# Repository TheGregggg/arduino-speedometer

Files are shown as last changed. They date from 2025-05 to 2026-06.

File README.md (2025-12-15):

# Arduino Speedometer
This is a speedometer for sim racing, built using an Arduino, a servo motor and a four-digit, eight-segment display.  

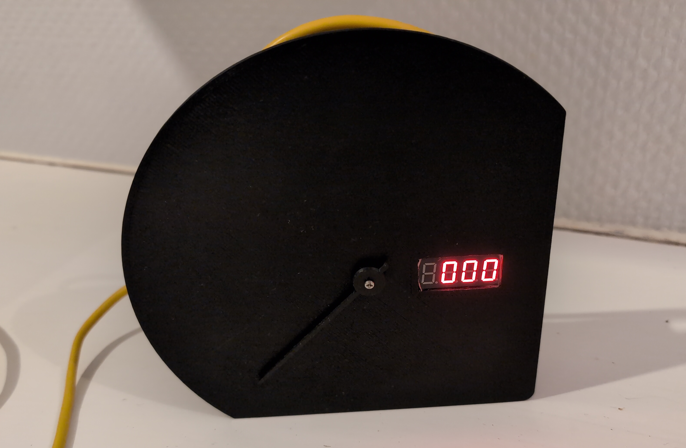
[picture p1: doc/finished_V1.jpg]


This speedometer displays analogue engine RPM via the servo motor and digital speed in km/h via the four-digit LED display.  

The server is programmed in C and currently support only Forza Horizon 4.
The game is configured to send data packets to the server. The server parses the packet and only uses the RPM and speed and send it to the Arduino via UART in a special byte format that compresses the RPM and the speed into 3 bytes.

## Planned improvements
- Update it to support other games, such as Forza Horizon 5 (not tested but should be straightforward) and Assetto Corsa (specific logic needs to be done for this game).  
- Improve visuals with a white dial across all the half circle.  
- Paint the needle red to make it more visible.  

# Build
I wanted to build something modular, reparable and with off the shelf components, specifically what I have lying around.

That's why I used an Arduino UNO as the microcontroller.
I also used a 3461BS as the 4 digits 8 segments display paired with a HC595 8 bit shift register.

The first prototype was realised with a breadboard and cardboard.
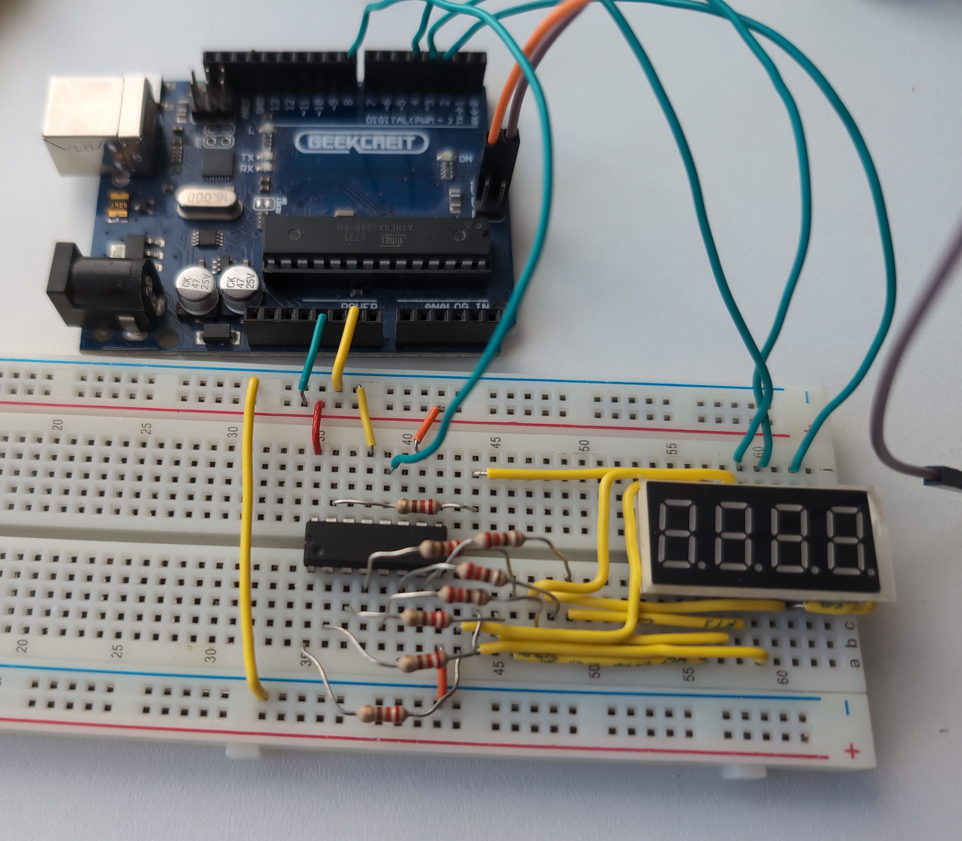
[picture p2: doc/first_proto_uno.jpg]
First protoype with the UNO and a breadboard

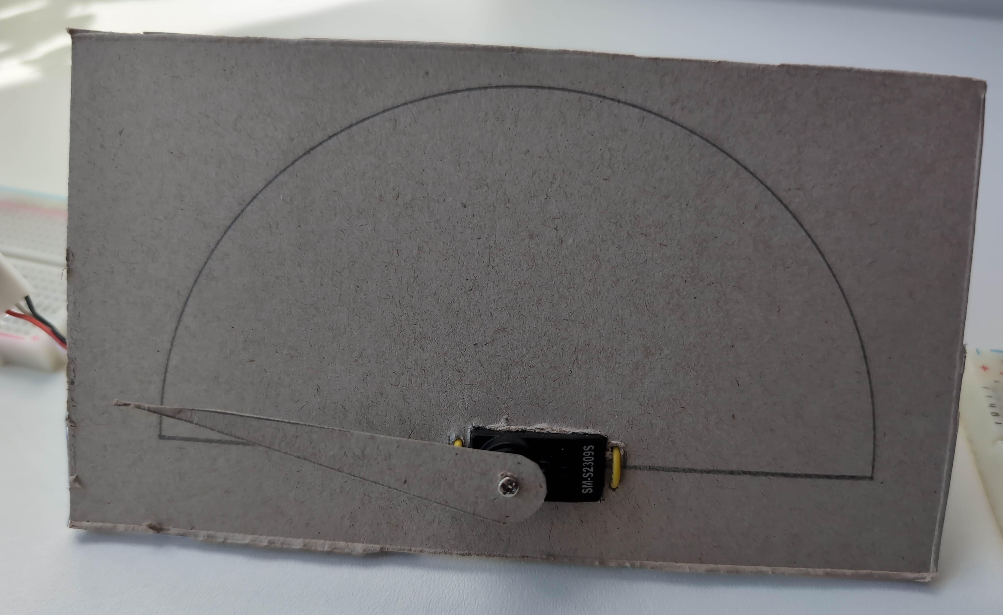
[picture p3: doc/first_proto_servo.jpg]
First protoype with the servo motor

*First prototype with all the components mounted on a breadboard and the servo attached to a cardboard dial*

I then created a custom board for all the components.
All the resistors, the DIP socket for the HC595 and a decoupling capacitor for the servo motor were mounted and soldered on a stripboard for a clean finished product.

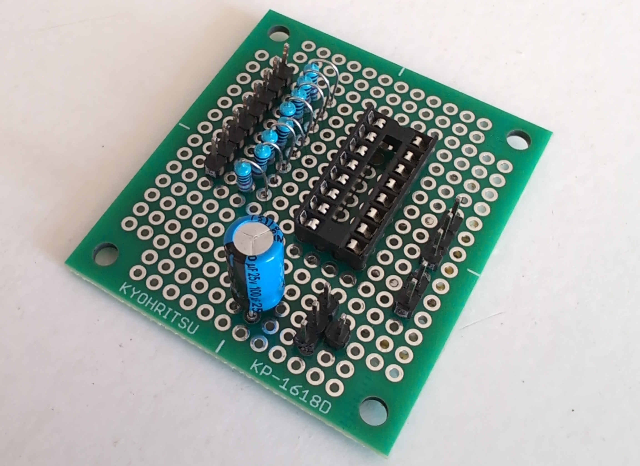
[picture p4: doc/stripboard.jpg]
Strip board with soldered components

*Hand soldered stripboard :) you don't want to look to the other way.*

Pins were also soldered to facilitate connections between this board and the Arduino and the 3461BS.

The custom board was tested with everything plugged in.
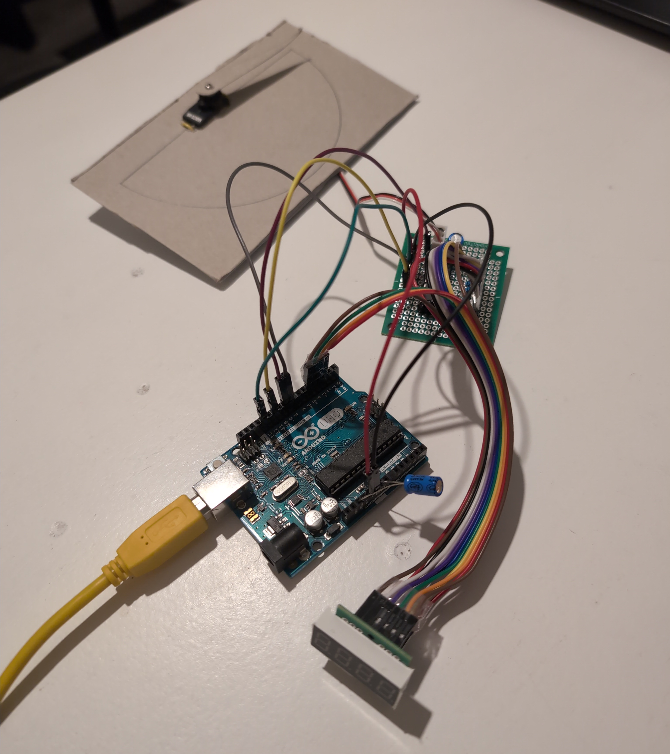
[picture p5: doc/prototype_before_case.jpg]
Prototype using the stripboard

*Prototype cardboard speedometer using the stripboard*

I designed the shell in FreeCAD to learn 3D modelling and then 3D printed it in PLA.
I then assembled everything into a tiny and neat product.

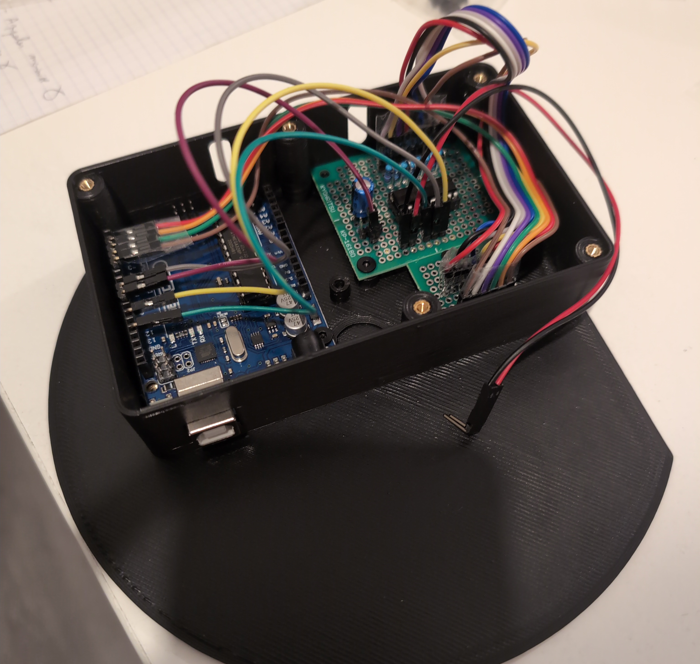
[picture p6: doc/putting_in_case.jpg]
Fitting all components inside the shell

*Fitting all components together in the tight shell. Threaded inserts were used to facilitate screw mounting of the components and to allow disassembly!*

# Work Reference
STEP files used as 3D reference for case design:  
- https://www.printables.com/model/360145-micro-servo-3d-model-stp/files
- https://www.printables.com/model/358867-arduino-uno-3d-model-stp/files

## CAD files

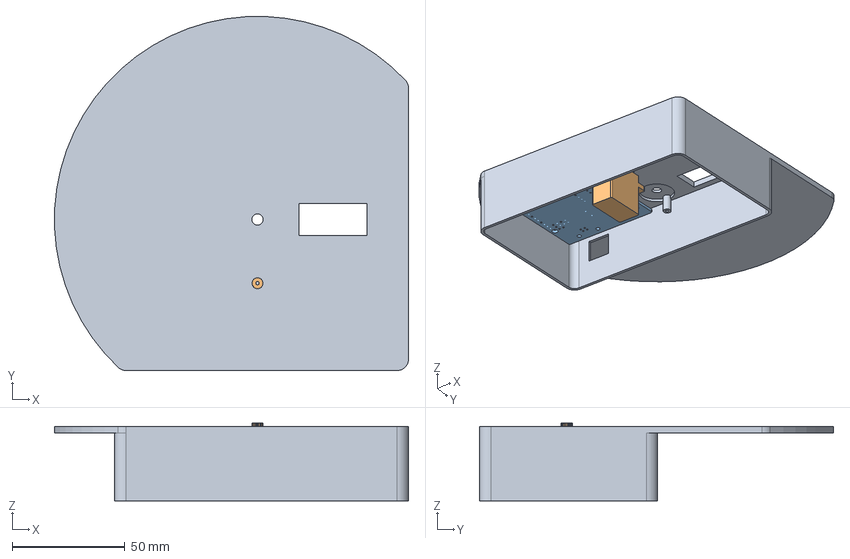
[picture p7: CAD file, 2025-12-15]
cad/shell_assembly.FCStd
156.8 x 156.8 x 34.5 mm
shell_Corps_001
SG90-Servo1_SG90-SERVO_001
UNO-TH_Rev3e1_001

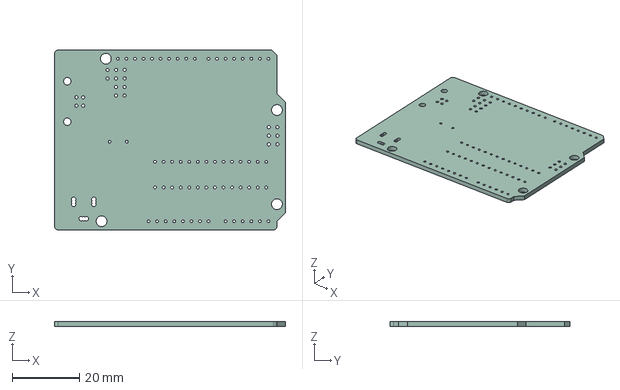
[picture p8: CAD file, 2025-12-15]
cad/A000066-cad-files/UNO-TH_Rev3e.step
68.6 x 53.3 x 1.51 mm

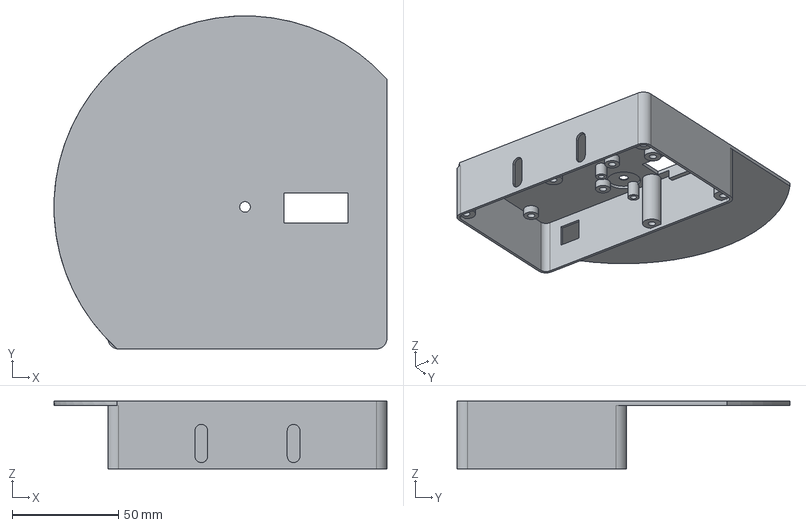
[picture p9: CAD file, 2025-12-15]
cad/shell-shell.step
156.9 x 156.8 x 32.0 mm

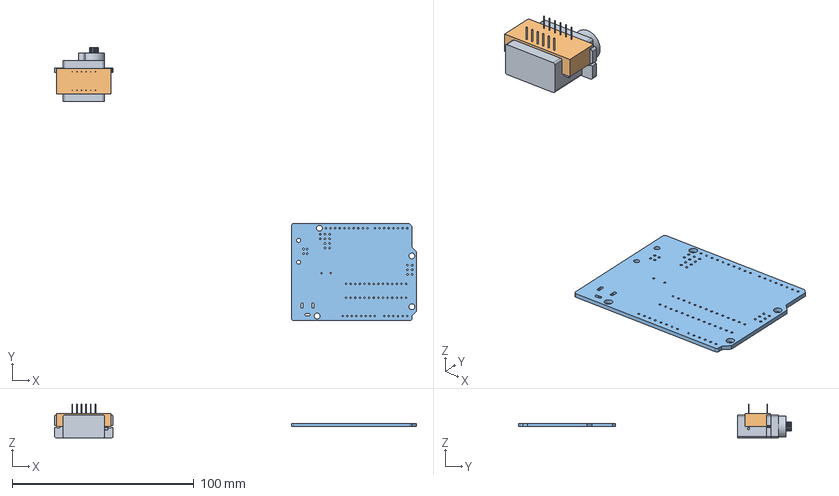
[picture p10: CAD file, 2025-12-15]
cad/shell.FCStd
198.9 x 150.2 x 18.4 mm
SG90-SERVO
Corps
UNO-TH_Rev3e_PCB

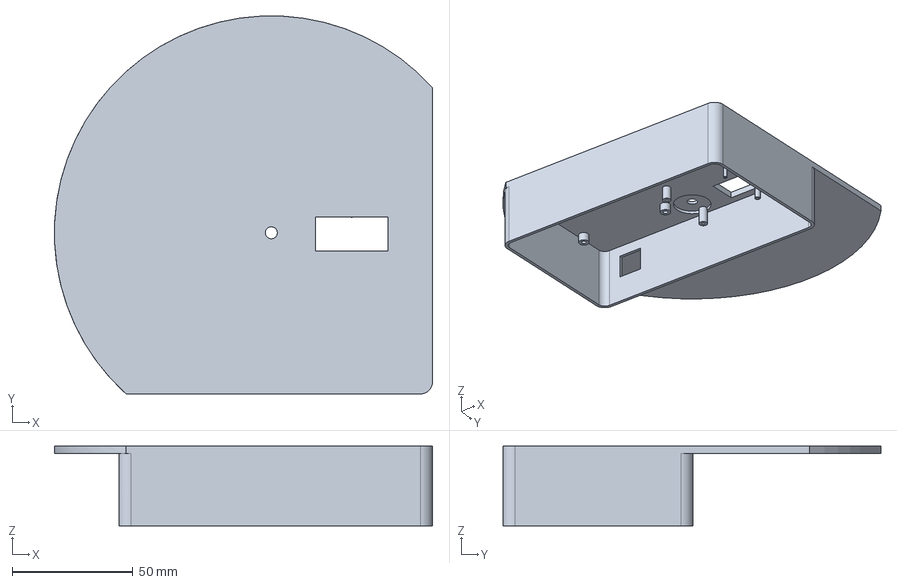
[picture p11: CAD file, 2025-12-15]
cad/shell.FCStd.bak.FCStd
156.8 x 156.8 x 33.0 mm

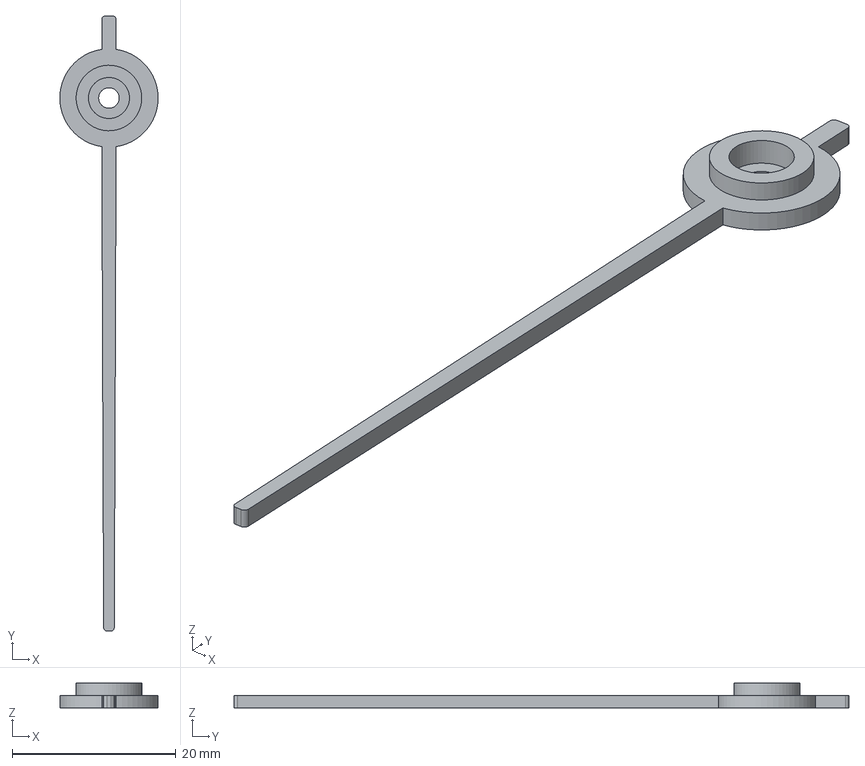
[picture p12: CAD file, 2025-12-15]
cad/aiguille.step
12.0 x 75.0 x 3.00 mm

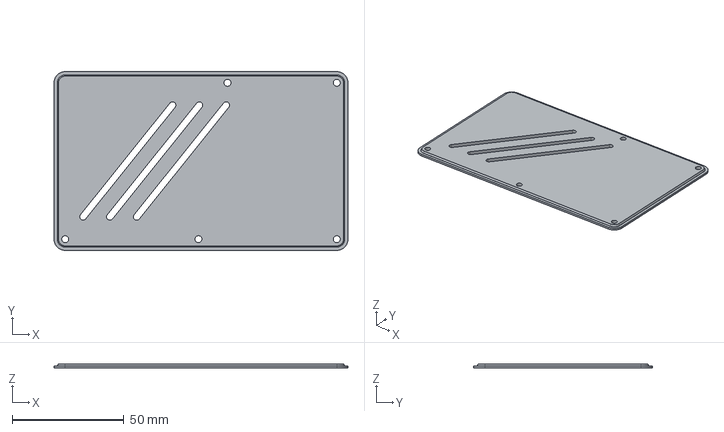
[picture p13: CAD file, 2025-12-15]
cad/shell-couvercle.step
131.5 x 79.9 x 2.00 mm

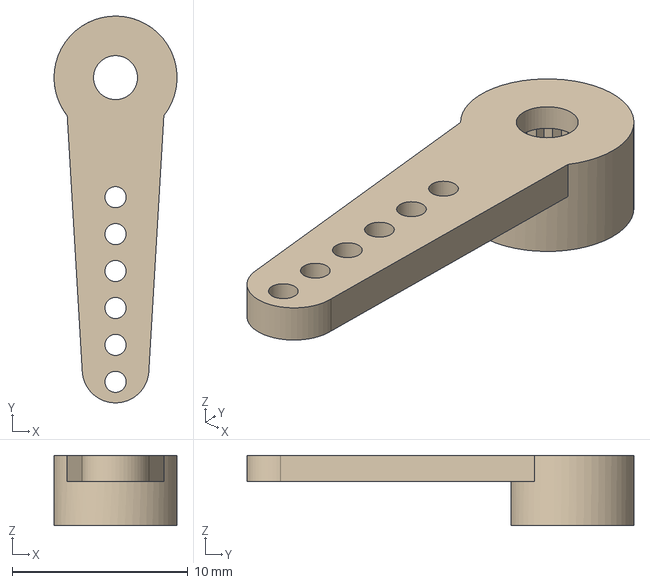
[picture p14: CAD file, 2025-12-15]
cad/SG90_Arm.step
7.00 x 22.0 x 4.00 mm

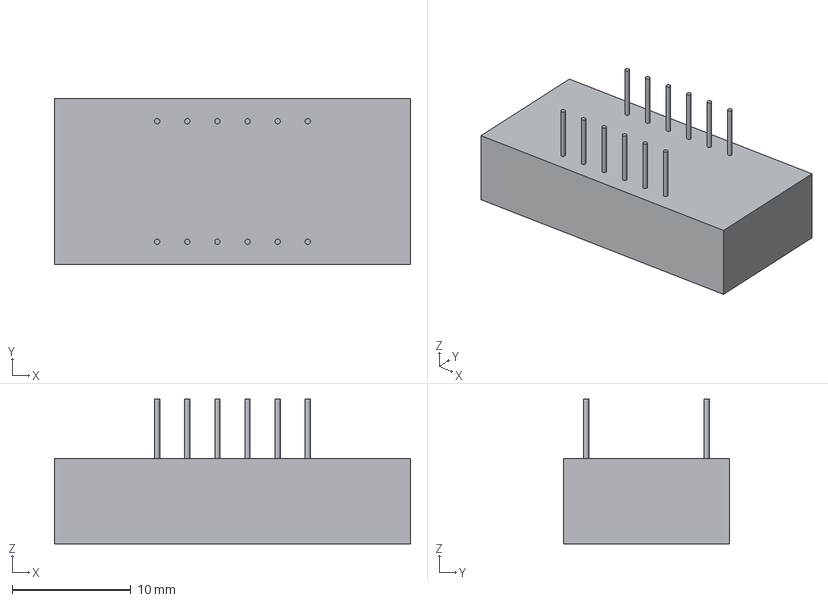
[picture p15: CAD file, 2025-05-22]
cad/3461AS.step
30.0 x 14.0 x 12.2 mm

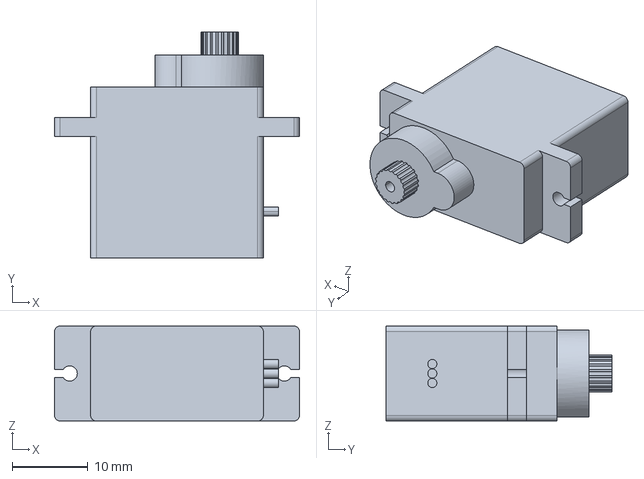
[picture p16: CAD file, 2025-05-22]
cad/SG90-Servo.stp
32.2 x 29.8 x 12.5 mm

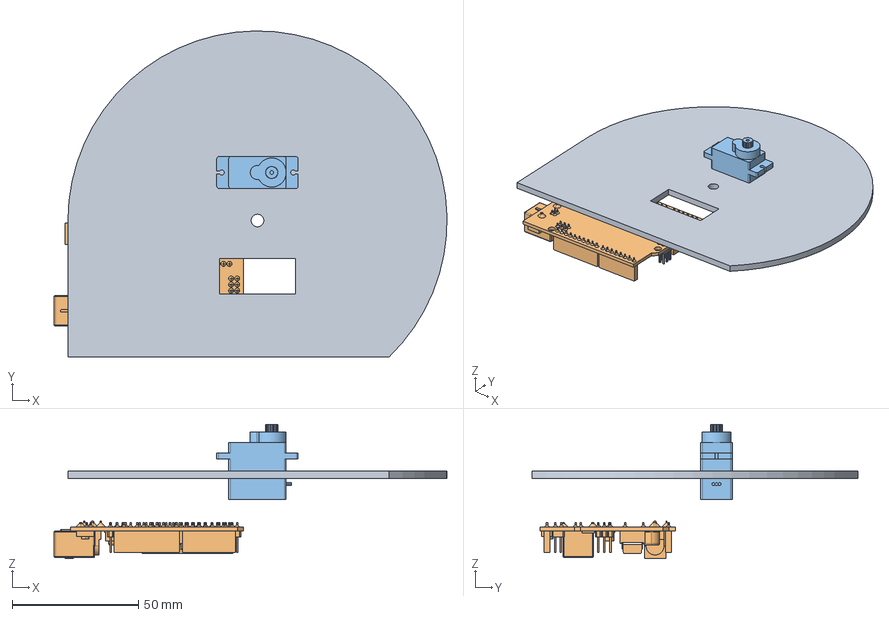
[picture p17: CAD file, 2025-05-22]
cad/shell.20250520-173400.FCStd
155.5 x 129.0 x 53.1 mm
Corps
ARDUINO-UNO
SG90-SERVO

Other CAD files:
cad/3461AS.FCStd
cad/aiguille.FCStd

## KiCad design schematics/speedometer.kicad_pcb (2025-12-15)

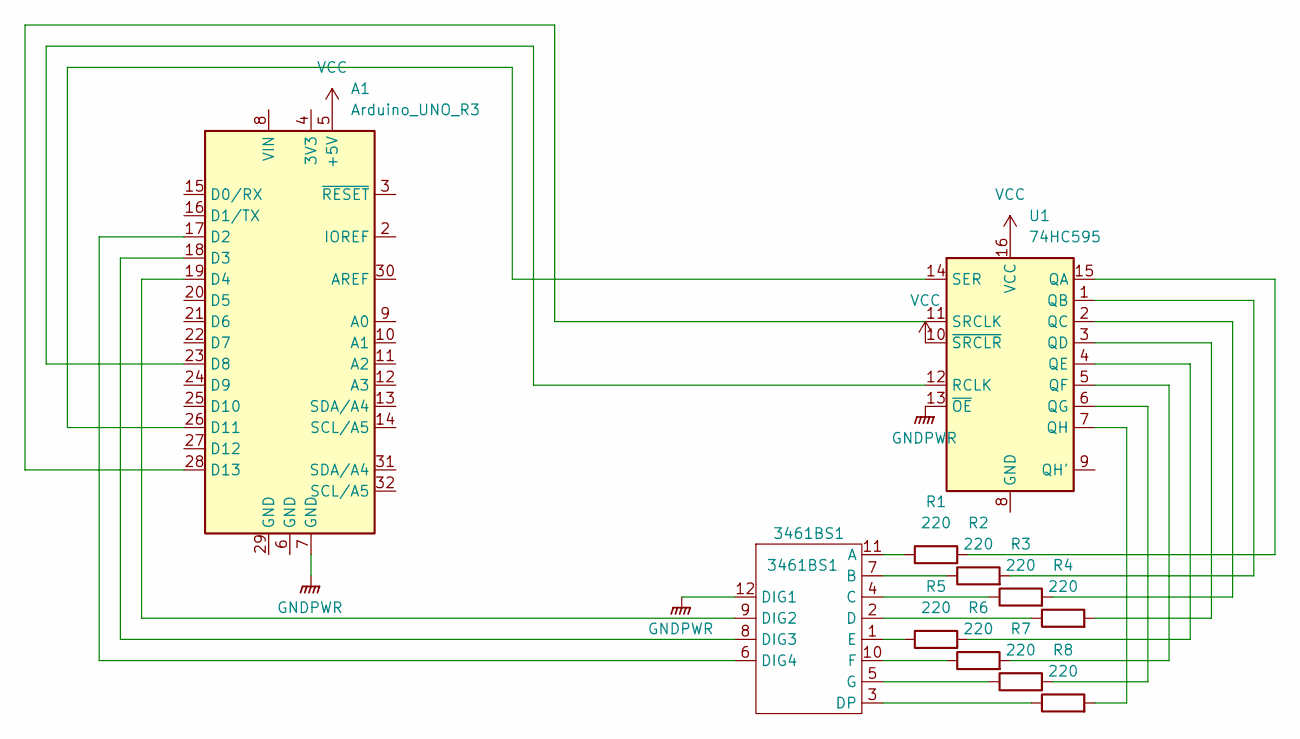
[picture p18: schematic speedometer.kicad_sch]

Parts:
3461BS1: 3461BS1; DIP-12_W7.62mm
A1: Arduino_UNO_R3
R1, R2, R3, R4, R5, R6, R7, R8: 220; R_Axial_DIN0204_L3.6mm_D1.6mm_P1.90mm_Vertical
U1: 74HC595; CERDIP-16_W7.62mm_SideBrazed

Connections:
GNDPWR: 3461BS1.12 (DIG1), A1.7 (GND), U1.13 (~OE)
unnamed: 3461BS1.11 (A), R1.1
unnamed: 3461BS1.7 (B), R2.1
unnamed: 3461BS1.4 (C), R3.1
unnamed: 3461BS1.2 (D), R4.1
unnamed: 3461BS1.9 (DIG2), A1.19 (D4)
unnamed: 3461BS1.8 (DIG3), A1.18 (D3)
unnamed: 3461BS1.6 (DIG4), A1.17 (D2)
unnamed: 3461BS1.3 (DP), R8.1
unnamed: 3461BS1.1 (E), R5.1
unnamed: 3461BS1.10 (F), R6.1
unnamed: 3461BS1.5 (G), R7.1
unnamed: A1.23 (D8), U1.12 (RCLK)
unnamed: A1.26 (D11), U1.14 (SER)
unnamed: A1.28 (D13), U1.11 (SRCLK)
unnamed: R1.2, U1.15 (QA)
unnamed: R2.2, U1.1 (QB)
unnamed: R3.2, U1.2 (QC)
unnamed: R4.2, U1.3 (QD)
unnamed: R5.2, U1.4 (QE)
unnamed: R6.2, U1.5 (QF)
unnamed: R7.2, U1.6 (QG)
unnamed: R8.2, U1.7 (QH)
VCC: A1.5 (+5V), U1.10 (~SRCLR), U1.16 (VCC)

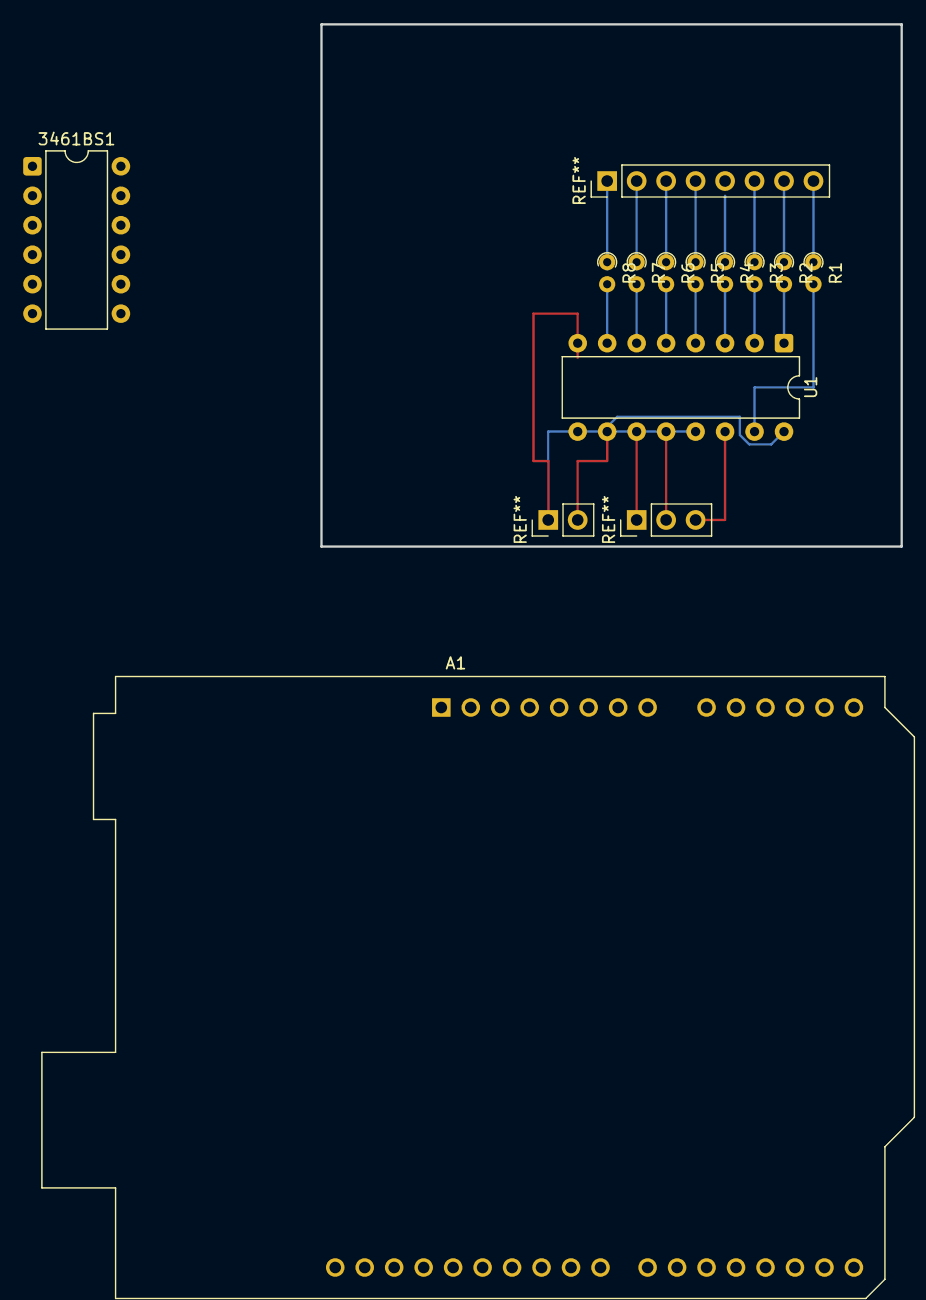
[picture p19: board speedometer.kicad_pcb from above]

Board: 2 copper layers, 50.0 x 45.0 mm, 11 parts (0 on the bottom side), 24 nets.

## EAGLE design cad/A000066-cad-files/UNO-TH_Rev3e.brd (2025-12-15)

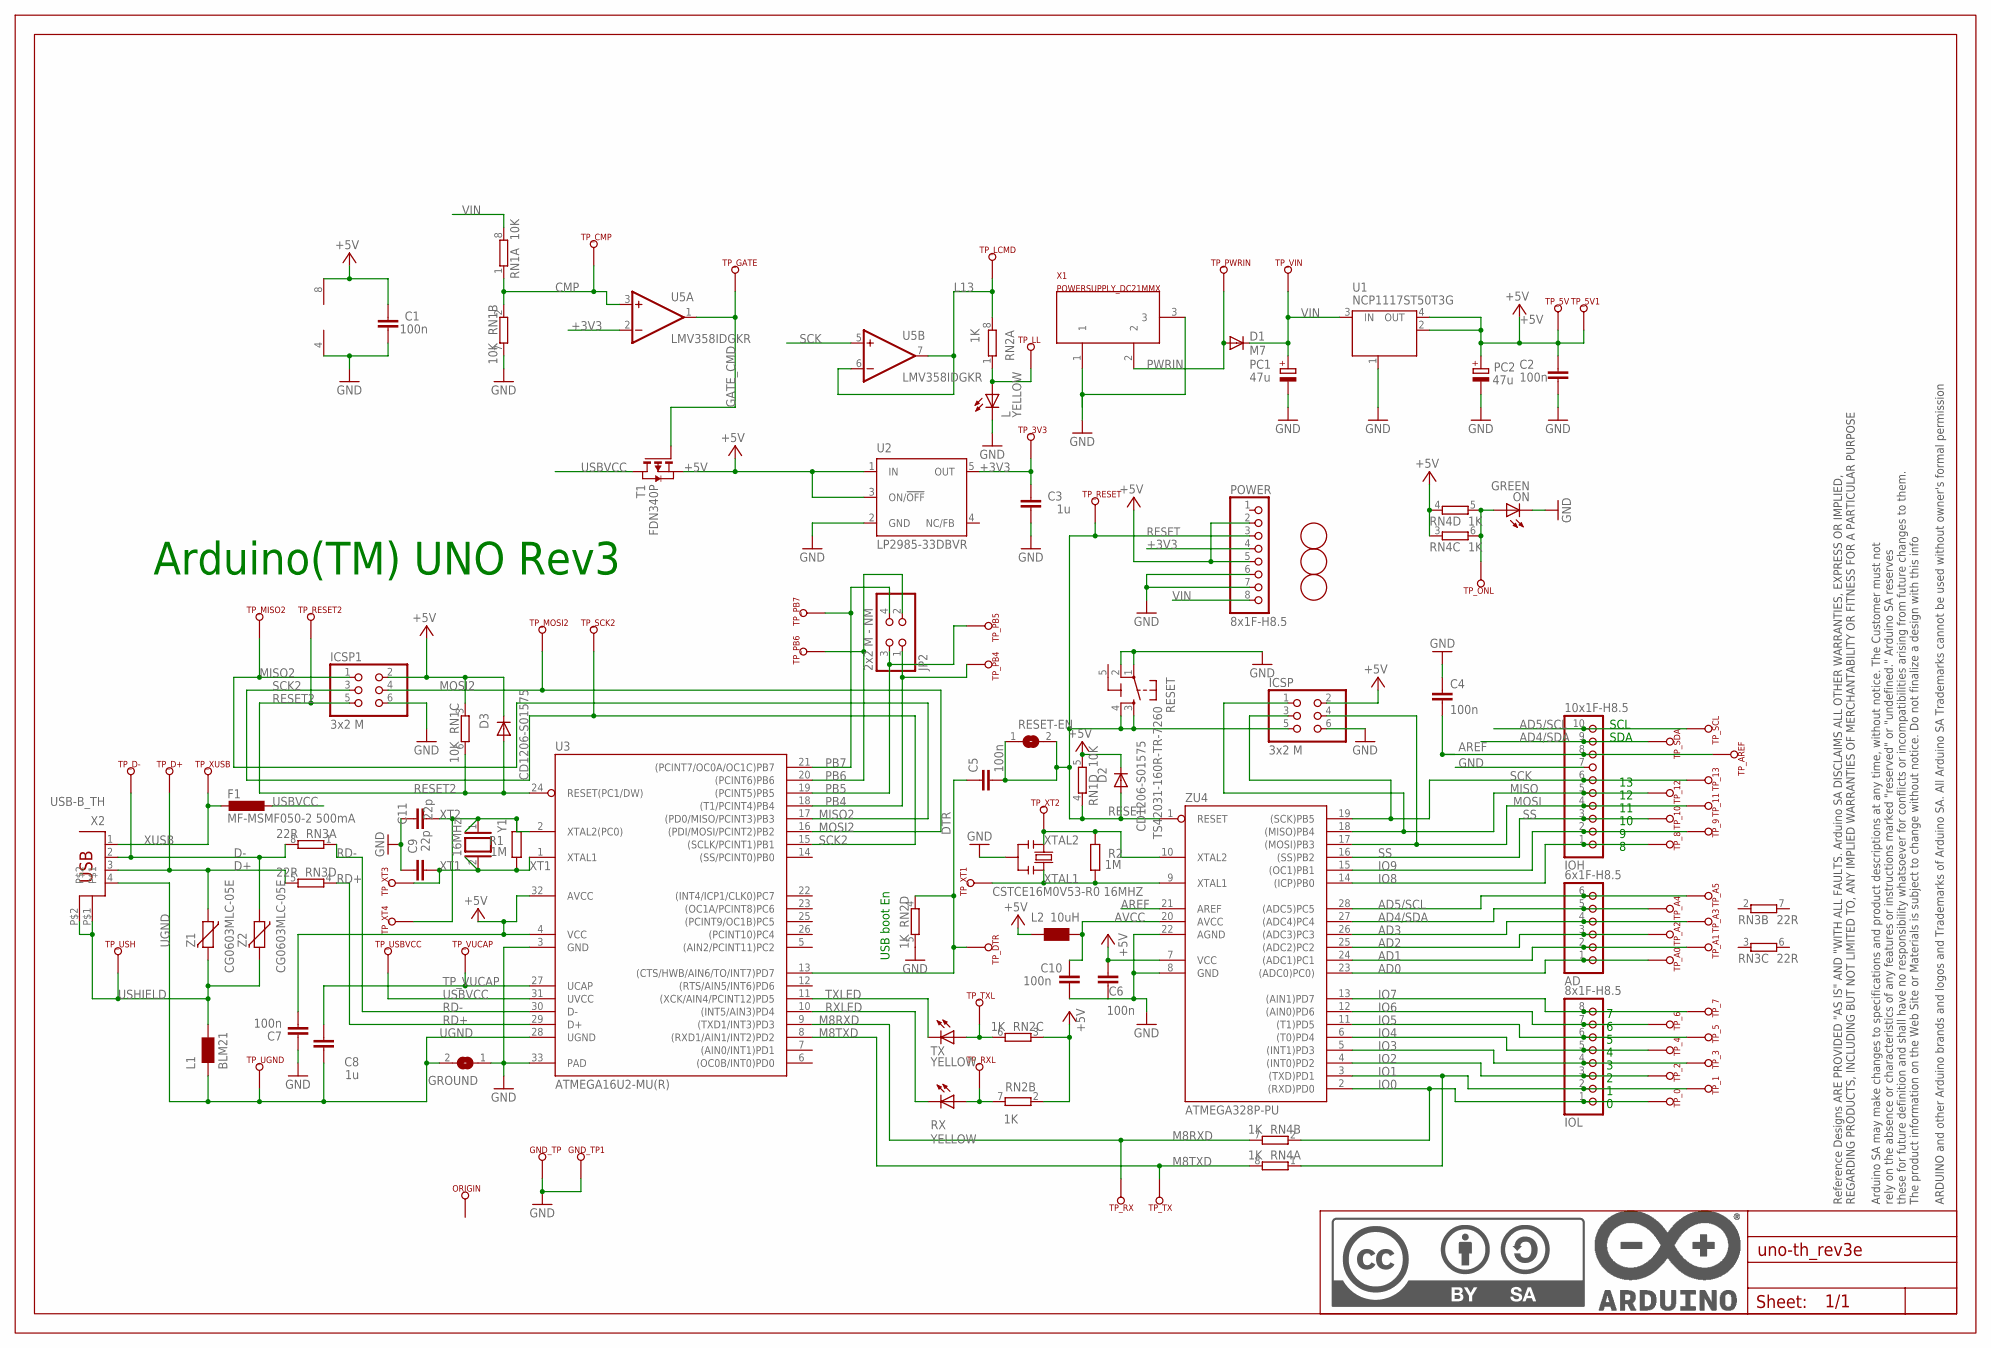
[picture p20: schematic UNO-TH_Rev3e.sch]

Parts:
AD: 6x1F-H8.5; 1X06
C1, C2, C4, C5, C6, C7, C10: 100n; C0603-ROUND
C3, C8: 1u; C0603-ROUND
C9, C11: 22p; C0603-ROUND
D1: M7; SMB
D2, D3: CD1206-S01575; MINIMELF
F1: MF-MSMF050-2 500mA; L1812
FD1, FD2, FD3: FIDUCIALMOUNT; FIDUCIA-MOUNT
FRAME1: DNP; FRAME
GND_TP, GND_TP1: TP_SP; TP-SP
GROUND: SJ
ICSP, ICSP1: 3x2 M; 2X03
IOH: 10x1F-H8.5; 1X10
IOL: 8x1F-H8.5; 1X08
JP2: 2x2 M - NM; 2X02
L: YELLOW; CHIP-LED0805
L1: BLM21; 0805
L2: 10uH; 0805
ON: GREEN; CHIP-LED0805
ORIGIN: TP_SP; TP-SP
PC1, PC2: 47u; PANASONIC_D
POWER: 8x1F-H8.5; 1X08
R1, R2: 1M; R0603-ROUND
RESET: TS42031-160R-TR-7260; TS42
RESET-EN: SJ
RN1: 10K; CAY16
RN2, RN4: 1K; CAY16
RN3: 22R; CAY16
RX: YELLOW; CHIP-LED0805
T1: FDN340P; SOT-23
TP_0, TP_1, TP_2, TP_3, TP_3V3, TP_4, TP_5, TP_5V, TP_5V1, TP_6, TP_7, TP_8, TP_9, TP_10, TP_11, TP_12, TP_13: TP_SP; TP-SP
TP_A0, TP_A1, TP_A2, TP_A3, TP_A4, TP_A5: TP_SP; TP-SP
TP_AREF: TP_SP; TP-SP
TP_CMP: TP_SP; TP-SP
TP_D+: TP_SP; TP-SP
TP_D-: TP_SP; TP-SP
TP_DTR: TP_SP; TP-SP
TP_GATE: TP_SP; TP-SP
TP_LCMD: TP_SP; TP-SP
TP_LL: TP_SP; TP-SP
TP_MISO2: TP_SP; TP-SP
TP_MOSI2: TP_SP; TP-SP
TP_ONL: TP_SP; TP-SP
TP_PB4, TP_PB5, TP_PB6, TP_PB7: TP_SP; TP-SP
TP_PWRIN: TP_SP; TP-SP
TP_RESET, TP_RESET2: TP_SP; TP-SP
TP_RX: TP_SP; TP-SP
TP_RXL: TP_SP; TP-SP
TP_SCK2: TP_SP; TP-SP
TP_SCL: TP_SP; TP-SP
TP_SDA: TP_SP; TP-SP
TP_TX: TP_SP; TP-SP
TP_TXL: TP_SP; TP-SP
TP_UGND: TP_SP; TP-SP
TP_USBVCC: TP_SP; TP-SP
TP_USH: TP_SP; TP-SP
TP_VIN: TP_SP; TP-SP
TP_VUCAP: TP_SP; TP-SP
TP_XT1, TP_XT2, TP_XT3, TP_XT4: TP_SP; TP-SP
TP_XUSB: TP_SP; TP-SP
TX: YELLOW; CHIP-LED0805
U1: NCP1117ST50T3G; SOT223
U2: LP2985-33DBVR; SOT23-DBV
U3: ATMEGA16U2-MU(R); MLF32
U5: LMV358IDGKR; MSOP08
X1: POWERSUPPLY_DC21MMX; POWERSUPPLY_DC-21MM
X2: USB-B_TH; PN61729
Y1: 16MHz; QS
Y2: CSTCE16M0V53-R0 16MHZ; RESONATOR
Z1, Z2: CG0603MLC-05E; CT/CN0603
ZU4: ATMEGA328P-PU; DIL28-3

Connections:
5-GND: RESET.5 (5-GND)
+3V3: C3.2, POWER.4, TP_3V3.X, U2.5 (OUT), U5.2 (-IN)
+5V: C1.2, C2.2, C6.2, C7.1, D2.C, D3.C, ICSP.2, ICSP1.2, L2.1, PC2.+, POWER.2, POWER.5, RN1.3 (1), RN1.5 (2), RN2.2 (1), RN2.3 (1), RN4.3 (1), RN4.4 (1), T1.2 (S), TP_5V.X, TP_5V1.X, U1.2 (OUT), U1.4 (OUT), U2.1 (IN), U2.3 (ON/!OFF), U3.4 (VCC), U3.32 (AVCC), U5.8 (V+), ZU4.7 (VCC)
AD0: AD.1, TP_A0.X, ZU4.23 ((ADC0)PC0))
AD1: AD.2, TP_A1.X, ZU4.24 ((ADC1)PC1)
AD2: AD.3, TP_A2.X, ZU4.25 ((ADC2)PC2)
AD3: AD.4, TP_A3.X, ZU4.26 ((ADC3)PC3)
AD4/SDA: AD.5, IOH.9, TP_A4.X, TP_SDA.X, ZU4.27 ((ADC4)PC4)
AD5/SCL: AD.6, IOH.10, TP_A5.X, TP_SCL.X, ZU4.28 ((ADC5)PC5)
AREF: C4.2, IOH.8, TP_AREF.X, ZU4.21 (AREF)
AVCC: C10.2, L2.2, ZU4.20 (AVCC)
CMP: RN1.1, RN1.2 (1), TP_CMP.X, U5.3 (+IN)
D+: RN3.5 (2), TP_D+.X, X2.3, Z1.1
D-: RN3.8 (2), TP_D-.X, X2.2, Z2.1
DTR: C5.1, RN2.4 (1), TP_DTR.X, U3.13 ((CTS/HWB/AIN6/TO/INT7)PD7)
GATE_CMD: T1.3 (G), TP_GATE.X, U5.1 (OUT)
GND: C1.1, C2.1, C3.1, C4.1, C6.1, C7.2, C9.2, C10.1, C11.2, GND_TP.X, GND_TP1.X, GROUND.1, ICSP.6, ICSP1.6, IOH.7, L.C, ON.C, PC1.-, PC2.-, POWER.6, POWER.7, RESET.1, RESET.2, RN1.7 (2), RN2.5 (2), U1.1 (GND/ADJ), U2.2 (GND), U3.3 (GND), U3.33 (PAD), U5.4 (V-), X1.1, X1.3, Y2.2, ZU4.8 (GND), ZU4.22 (AGND)
IO0: IOL.1, RN4.2 (1), TP_0.X, ZU4.2 ((RXD)PD0)
IO1: IOL.2, RN4.1, TP_1.X, ZU4.3 ((TXD)PD1)
IO2: IOL.3, TP_2.X, ZU4.4 ((INT0)PD2)
IO3: IOL.4, TP_3.X, ZU4.5 ((INT1)PD3)
IO4: IOL.5, TP_4.X, ZU4.6 ((T0)PD4)
IO5: IOL.6, TP_5.X, ZU4.11 ((T1)PD5)
IO6: IOL.7, TP_6.X, ZU4.12 ((AIN0)PD6)
IO7: IOL.8, TP_7.X, ZU4.13 ((AIN1)PD7)
IO8: IOH.1, TP_8.X, ZU4.14 ((ICP)PB0)
IO9: IOH.2, TP_9.X, ZU4.15 ((OC1)PB1)
L13: RN2.8 (2), TP_LCMD.X, U5.6 (-IN), U5.7 (OUT)
M8RXD: RN4.7 (2), TP_RX.X, U3.9 ((TXD1/INT3)PD3)
M8TXD: RN4.8 (2), TP_TX.X, U3.8 ((RXD1/AIN1/INT2)PD2)
MISO: ICSP.1, IOH.5, TP_12.X, ZU4.18 ((MISO)PB4)
MISO2: ICSP1.1, TP_MISO2.X, U3.17 ((PD0/MISO/PCINT3)PB3)
MOSI: ICSP.4, IOH.4, TP_11.X, ZU4.17 ((MOSI)PB3)
MOSI2: ICSP1.4, TP_MOSI2.X, U3.16 ((PDI/MOSI/PCINT2)PB2)
unnamed: L.A, RN2.1, TP_LL.X
unnamed: ON.A, RN4.5 (2), RN4.6 (2), TP_ONL.X
unnamed: RN2.7 (2), RX.A, TP_RXL.X
unnamed: RN2.6 (2), TP_TXL.X, TX.A
PB4: JP2.1, TP_PB4.X, U3.18 ((T1/PCINT4)PB4)
PB5: JP2.3, TP_PB5.X, U3.19 ((PCINT5)PB5)
PB6: JP2.2, TP_PB6.X, U3.20 ((PCINT6)PB6)
PB7: JP2.4, TP_PB7.X, U3.21 ((PCINT7/OC0A/OC1C)PB7)
PWRIN: D1.A, TP_PWRIN.X, X1.2
RD+: RN3.4 (1), U3.29 (D+)
RD-: RN3.1, U3.30 (D-)
RESET: C5.2, D2.A, ICSP.5, POWER.3, RESET.3, RESET.4, RESET-EN.1, RESET-EN.2, RN1.4 (1), TP_RESET.X, ZU4.1 (RESET)
RESET2: D3.A, ICSP1.5, RN1.6 (2), TP_RESET2.X, U3.24 (RESET(PC1/DW))
RXLED: RX.C, U3.10 ((INT5/AIN3)PD4)
SCK: ICSP.3, IOH.6, TP_13.X, U5.5 (+IN), ZU4.19 ((SCK)PB5)
SCK2: ICSP1.3, TP_SCK2.X, U3.15 ((SCLK/PCINT1)PB1)
SS: IOH.3, TP_10.X, ZU4.16 ((SS)PB2)
TP_VUCAP: C8.1, TP_VUCAP.X, U3.27 (UCAP)
TXLED: TX.C, U3.11 ((XCK/AIN4/PCINT12)PD5)
UGND: C8.2, GROUND.2, L1.1, TP_UGND.X, U3.28 (UGND), X2.4
USBVCC: F1.1, T1.1 (D), TP_USBVCC.X, U3.31 (UVCC)
USHIELD: L1.2, TP_USH.X, X2.P$1, X2.P$2, Z1.2, Z2.2
VIN: D1.C, PC1.+, POWER.8, RN1.8 (2), TP_VIN.X, U1.3 (IN)
XT1: C9.1, R1.1, TP_XT3.X, U3.1 (XTAL1), Y1.2
XT2: C11.1, R1.2, TP_XT4.X, U3.2 (XTAL2(PC0)), Y1.1
XTAL1: R2.1, TP_XT1.X, Y2.3, ZU4.9 (XTAL1)
XTAL2: R2.2, TP_XT2.X, Y2.1, ZU4.10 (XTAL2)
XUSB: F1.2, TP_XUSB.X, X2.1

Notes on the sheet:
Arduino(TM) UNO Rev3
USB boot En
SDA
SCL

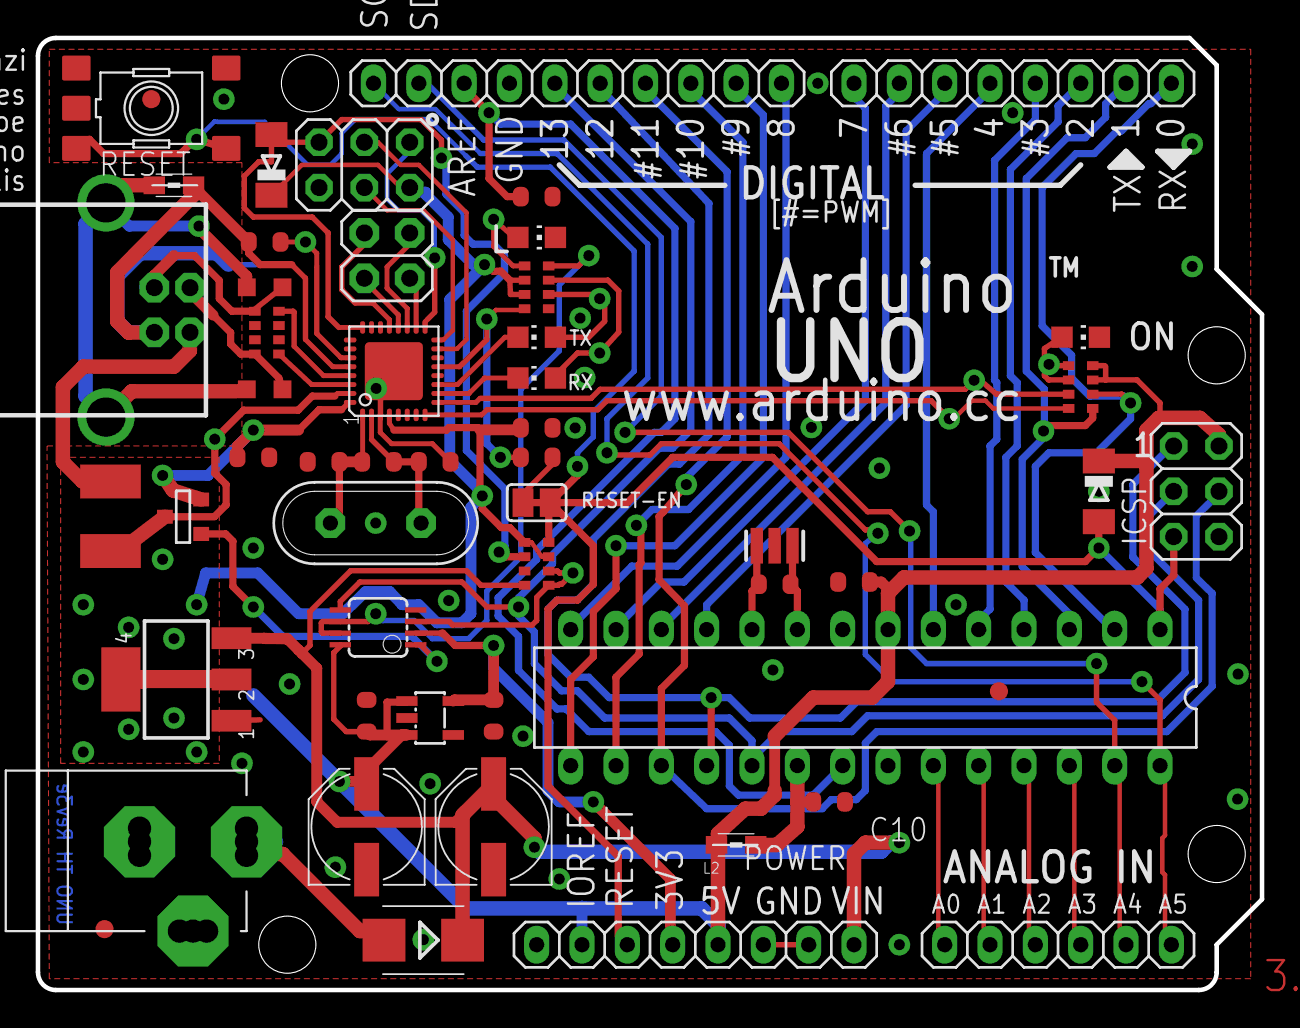
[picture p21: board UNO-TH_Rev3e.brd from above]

Board: 2 copper layers, 68.6 x 53.3 mm, 116 parts (1 on the bottom side), 61 nets.

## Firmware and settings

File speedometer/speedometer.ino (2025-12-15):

#define RegisterCLK 8
#define Digit4 2
#define Digit3 3
#define Digit2 4
#define Digit1 5
#define ledPin 13
#define SERIAL_BUFFER_SIZE 3

#include <SPI.h>
#include <Servo.h>

Servo myservo;


unsigned char Servo_pos = 0;  // variable to store the servo position
unsigned char serial_rpm=10;
unsigned int serial_speed=10;
unsigned int max_rpm = 100;

unsigned int NUMBER_TO_LED[10] = {
  0b00111111, // 0
  0b00000110, // 1
  0b01011011, // 2
  0b01001111, // 3
  0b01100110, // 4
  0b01101101, // 5
  0b01111101, // 6
  0b00000111, // 7
  0b01111111, // 8
  0b01101111 //9
};

unsigned int CURRENT_DIGIT = 0;

unsigned int SPEED[3] = {0,0,0};

unsigned char serial_buffer[SERIAL_BUFFER_SIZE];
unsigned char read_byte;
unsigned char serial_buffer_index;
unsigned char valide_start=0;


void setSPEED_BCD(unsigned int nb){
  SPEED[2] = nb/100;
  SPEED[1] = (nb%100)/10;
  SPEED[0] = (nb%10);
}

void startupSequence(){
  myservo.write(180);
  delay(750);
  myservo.write(0);
  delay(750);
  myservo.write(180);
}

void setupTimer2(){
  // setup the Timer 2 for a 300 Hz clock to switch into the next digit
  noInterrupts();           // disable all interrupts
  TCCR2A = 0;
  TCCR2B = 0;
  TCNT2  = 0;

  OCR2A = 208;            // compare match register 16MHz/(256*300Hz)
  TCCR2B |= (1 << WGM22);   // CTC mode
  TCCR2B |= (1 << CS22);    
  TCCR2B |= (1 << CS21);    
  TCCR2B |= (0 << CS20);    // 256 prescaler 
  TIMSK2 |= (1 << OCIE2A);  // enable timer compare interrupt
  interrupts();             // enable all interrupts
}

void setup() {
  // Setup Register CLK
  pinMode(RegisterCLK, OUTPUT);
  digitalWrite(RegisterCLK, 0);

  // Setup Digits pins
  pinMode(Digit1, OUTPUT);
  pinMode(Digit2, OUTPUT);
  pinMode(Digit3, OUTPUT);
  pinMode(Digit4, OUTPUT);
  
  digitalWrite(Digit1, 0);
  digitalWrite(Digit2, 0);
  digitalWrite(Digit3, 0);
  digitalWrite(Digit4, 0);

  myservo.attach(9);  // attaches the servo on pin 9 to the servo object
  Serial.begin(2000000);


  SPI.begin();
  SPI.beginTransaction(SPISettings(40000000, MSBFIRST, SPI_MODE0));
 
  setupTimer2();

  startupSequence();
}

ISR(TIMER2_COMPA_vect)          // interrupt being called at 300hz 
{
  CURRENT_DIGIT = (CURRENT_DIGIT+1)%3; // light up the right digit in the 4 digit 8 segment display
  switch (CURRENT_DIGIT){
    case 0:
    digitalWrite(Digit4, 1);
    digitalWrite(Digit2, 0);
    break;
    
    case 1:
    digitalWrite(Digit4, 0);
    digitalWrite(Digit3, 1);
    break;
    
    case 2:
    digitalWrite(Digit3, 0);
    digitalWrite(Digit2, 1);
    break;
  }
  
  SPI.transfer(~(NUMBER_TO_LED[SPEED[CURRENT_DIGIT]]));  // send the new bytes to the serial in parallel out
  digitalWrite(RegisterCLK, 1); // register the new command into the  serial in parallel out shifter
  digitalWrite(RegisterCLK, 0);

  
}



void loop() {
  if (Serial.available() > 0) {
    read_byte = Serial.read();
    if(read_byte==255){
      if(valide_start == 0){
        //start packet read
        serial_buffer_index=0;
        valide_start=1;
      }else{
        //error stop packet read
        valide_start=0;
      }
    }
    else if(valide_start==1){
      if(read_byte==254){ //check if stop byte
        if(serial_buffer_index==3){ //check if all packed as been read and applyes the changes
          serial_speed= (serial_buffer[0]<<5) + serial_buffer[1]; 
          setSPEED_BCD(serial_speed);

          serial_rpm = serial_buffer[2];
          myservo.write(180-(((unsigned int)serial_rpm * 150) / max_rpm));
        }
        valide_start=0;
      }else{
        serial_buffer[serial_buffer_index]=read_byte;
        serial_buffer_index++;
      }
    }
  }
}

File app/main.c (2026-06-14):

#include <stdint.h>
#include <stdio.h>
#include <string.h>
#include <pthread.h>

// Linux headers
#include <fcntl.h> 
#include <errno.h>
#include <sys/types.h>
#include <termios.h>
#include <unistd.h> 
#include <arpa/inet.h>
#include <sys/socket.h>

#include "forza_horizon.h"

#define ANSI_RED "\e[0;31m"
#define ANSI_GREEN "\e[0;32m"
#define ANSI_RESET "\e[0m"

#define NOT_CONNECTED_STRING ANSI_RED "not connected" ANSI_RESET
#define CONNECTED_STRING ANSI_GREEN "connected" ANSI_RESET

#define PORT 5000

int configure_serial(char * file, int bauds) {
	int serial_port = open(file, O_RDWR);
	struct termios tty;
	if (serial_port < 0) {
		fprintf(stderr, "Erreur à l'ouverture du fichier %s\n", file);
		return -1;
	}
	
	// Initialisation de la structure tty
	if(tcgetattr(serial_port, &tty) != 0) {
		fprintf(stderr,"Error %i from tcgetattr: %s\n", errno, strerror(errno));
		return -1;
	}

	//tty.c_cflag &= ~PARENB; // Pas de bit de parité
	tty.c_cflag &= ~CSTOPB; // 1 bit stop
	tty.c_cflag &= ~CSIZE; // 8 bits de données (cleat + set)
	tty.c_cflag |= CS8; 
	tty.c_cflag &= ~CRTSCTS; // Désactiver RTS/CTS
	tty.c_cflag |= CREAD | CLOCAL; // Activation de la lecture et on ignore les inst. de contrôle

	tty.c_lflag |= ICANON; // lecture caractère par caractère et non ligne par ligne
	tty.c_lflag &= ~ECHO; // Pas d'écho
	tty.c_lflag &= ~ECHOE;
	tty.c_lflag &= ~ECHONL;
	tty.c_lflag &= ~ISIG; // On n'interpête pas les caractères INTR, QUIT and SUSP
	tty.c_iflag &= ~(IXON | IXOFF | IXANY); // Désactiver le contrôle de flux logiciel
	tty.c_iflag &= ~(IGNBRK|BRKINT|PARMRK|ISTRIP|INLCR|IGNCR|ICRNL); // Pas de traitement des octets de contrôle

	// tty.c_oflag &= ~OPOST; // Prevent special interpretation of output bytes (e.g. newline chars)
	// tty.c_oflag &= ~ONLCR; // Prevent conversion of newline to carriage return/line feed
	// tty.c_oflag &= ~OXTABS; // Prevent conversion of tabs to spaces (NOT PRESENT ON LINUX)
	// tty.c_oflag &= ~ONOEOT; // Prevent removal of C-d chars (0x004) in output (NOT PRESENT ON LINUX)

	tty.c_cc[VTIME] = 100;    // Lecture bloquante, avec un timeout de 10 secondes (unité : 0.1 s)
	tty.c_cc[VMIN] = 0;

	// Vitesse 
	cfsetispeed(&tty, bauds);
	//cfsetospeed(&tty, bauds);

	// Enregistrement des réglages
	if (tcsetattr(serial_port, TCSANOW, &tty) != 0) {
		fprintf(stderr,"Error %i from tcsetattr: %s\n", errno, strerror(errno));
		return -1;
	}
	return serial_port; 
}

float getFloat(char* buffer, uint offset){
	return *((float*)&(buffer[offset]));
}

static uint8_t running = 1;

static uint8_t is_game_connected = 0;

static float received_speed = 0;
static float received_rpm = 0;

void* uart_part(){
	int serial_port; 
	unsigned char serialbuffer[5];

	serialbuffer[0] = 255; // start 
	serialbuffer[4] = 254; // end

	// Ouverture du port série
	serial_port=configure_serial("/dev/ttyACM0", B2000000);
	if (serial_port < 0) pthread_exit(NULL);

	sleep (3);  // attendre le redemrage du uno

	while(running){
		// convert data for UART transmition
		u_int16_t speed_bytes = (uint16_t)(received_speed*3.6);
		
		// split into 5 and 5 bits so that none of the high and low part can go to 255 and thus be used as end marquer
		u_int8_t speed_bytes_h = (speed_bytes>>5)  & 0b00011111; // 5 upper bits
		u_int8_t speed_bytes_l = speed_bytes & 0b00011111; // 5 lower bits
		
		u_int8_t rpm_byte = received_rpm/100;

		serialbuffer[1] = speed_bytes_h;
		serialbuffer[2] = speed_bytes_l;
		serialbuffer[3] = rpm_byte;
		write(serial_port,&serialbuffer,sizeof(serialbuffer));

	}

	close(serial_port);

	return NULL;
}

void* server_part(){
	// Buffer pour stocker les données lues
	

	return NULL;
}


void write_status(){
	printf("\r\033[A\033[2K"); // cusror at the begining of line, cursor move up and erase line
	printf("Game: %s \t Arduino: %s\n", is_game_connected == 1 ? CONNECTED_STRING : NOT_CONNECTED_STRING, NOT_CONNECTED_STRING);
}

int main(void) {
	pthread_t uart_thread;

	printf("Sim racing Speed-o-meter Server - Made by Greg\n");

	printf("\n");
	write_status();

	// pthread_create(&uart_thread, NULL, uart_part, NULL);

	char buffer[512];

	int listenfd;
	socklen_t len;

	struct sockaddr_in servaddr, cliaddr;
	bzero(&servaddr, sizeof(servaddr));

	// Create a UDP Socket
	listenfd = socket(AF_INET, SOCK_DGRAM, 0);        
	servaddr.sin_addr.s_addr = htonl(INADDR_ANY);
	servaddr.sin_port = htons(PORT);
	servaddr.sin_family = AF_INET; 

	// bind server address to socket descriptor
	bind(listenfd, (struct sockaddr*)&servaddr, sizeof(servaddr));
		
	//receive the datagram
	len = sizeof(cliaddr);

	while(running){
		int n = recvfrom(listenfd, buffer, sizeof(buffer),
				0, (struct sockaddr*)&cliaddr,&len); //receive message from server
		if (n == -1) continue; // error

		if (n != 324) continue; // not Forza Horizon 4/5/6 packet

		if (is_game_connected == 0){
			is_game_connected = 1;
			write_status();
		}

		// retrieve data form received buffer
		received_speed = getFloat(buffer, Speed);
		received_rpm = getFloat(buffer, CurrentEngineRpm); 
	}
	
	close(listenfd);

	pthread_join(uart_thread, NULL);
	
	return 0;
}

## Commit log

2025-05-08 arduino code and python begin
2025-05-22 CAD shell first draft
    [3461AS.FCStd, 3461AS.step, SG90-Servo.stp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]
2025-05-29 update 3d model
    [shell.FCStd]
2025-07-06 new version of 3d model ongoing
    [shell.FCStd, shell_assembly.FCStd]
2025-12-15 add cad files
    [SG90_Arm.step, UNO-TH_Rev3e.brd, UNO-TH_Rev3e.sch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]
2025-12-15 add schematics files in KiCAD
    [speedometer.kicad_pcb, speedometer.kicad_sch]
2025-12-15 add common anode LED datasheet
2025-12-15 fixe for final assembly with anode led 4 digit
    [speedometer.ino]
2026-06-14 renamed server to main, started working on thread and tui feedback

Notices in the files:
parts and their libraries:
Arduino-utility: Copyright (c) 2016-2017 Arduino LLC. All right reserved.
